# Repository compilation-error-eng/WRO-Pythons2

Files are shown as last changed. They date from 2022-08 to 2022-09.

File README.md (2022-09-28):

# WRO FUTURE ENGINEERS The Pythons 2 

This is a detailed documentation of our project in the WRO FUTURE ENGINEERS competition of my team that consist of 3 people and our coach Omar Khaled Elsayed . My name is Ahmed Elsayed and I am responsible for the programming of the robot , my teammates are Nour Eldin Raoof and Eyad Ahmed Nazary each are responsible for the mechanical and the electrical section of the robot respectively . We are from Egypt and are joining the WRO competition for the first time and I am going to explain the steps and procedures that went into creating our robot.

## Firstly: Our components
For seeing the blocks and moving accordingly we used the Openmv H7 plus camera module it is a cheap easy to buy camera module that is similar to the raspberry pi but is much cheaper here is a photo of it:

openmv1

>Link of components can be found at the end

For communicating with the camera module and order the motors to move accordingly we used an ordinary Arduino Nano 
A photo of it:

index

>Link can be found later

We used the l298 motor driver to move the motor forward and backwards and it is small and suitable for one motor which is required

f636e246-1f8f-4bf6-931c-e3b472912639 __CR00970600_PT0_SX970_V1___

For the battery we used a standard 12volt battery with 3600mah

For our steering mechanism we used a servo motor connected to a rod that controls the position of the robot.

YM2758-arduino-compatible-9g-micro-servo-motorImageMain-515 

We also used an IMU sensor to control the deviation of the robot from its origin point in certain turns 

imu sensor 

We used a stepdown buck converter DC to DC to convert the 12volts that are coming from the battery to 9 volts in order for the Arduino Nano to use it

buck convertor

## Links:

Arduino Nano:
https://store.arduino.cc/products/arduino-nano

l298 motordriver:
https://store.fut-electronics.com/products/l298-dual-motor-driver-module-2a

IMU sensor:
https://makerselectronics.com/product/imu-mpu-6050-gyroscope-accelerometer-sensor-module

buck cnovertor:
https://makerselectronics.com/product/xl4015-step-down-dc-module-with-cv-cc-control

servo motor:
https://makerselectronics.com/product/micro-servo-sg92r

openmv H7 R2 camera:
https://openmv.io/products/openmv-cam-h7-r2

## Explenation for the code:

we divided the code into steps :
- Blocks
- lines
- walls

ordered according to priority

I will now explain each step briefly:

### Blocks:

------------
we used a simple searching algorithm where the camera search in aspecified ROI (Region Of Intrest)
and applied a threshold for the camera to see only the specified color which is either Green or red if u want to see the blocks and that threshold can be changed in order to see diffrent colors and do diffrent tasks so we used this for the rest of the algorithm
, but there is a twist in the blocks part of the code it is important to make the blocks the highest priority so it can turn around it even if there is a line

### Lines:

------------
In the lines it was a little diffrent from the blocks because u have two lines with diffrent colours and u need to turn according to the first one the camera sees and u can simply do that with flags and counters ,make a counter that starts counting when it sees orange (or blue if u started in the opposite direction )
then if that counter gets high enough that means that he needs to turn the next time he sees a line otherwise dont turn and we also used the IMU MPU 6050 sensor to calculate degree of turn and made him turn only 45 degrees so he turns according to the block if there is one

### Walls:

------------
in the walls it was pretty simple but because of my camera was a little bugged it only saw one wall ond rarely sees the two lines togethor so i modified the 
original algorithm to suite my bugged camera which is always easier than getting a new camera i made , but isnt necessary, I write 3 conditions in total if the robot sees only the right wall it will position itself according to it , if it sees only the left wall it will also posistion itself accordingly  and if it sees the 2 walls togethor
(which rarely happens) this algorithm works but ofcourse it does have its bugs but i cant really afford a new camera so im sticking with this until i afford it

# electric schematic of the robot:

WRO schematic

# pictures of robot:

### Front view:

-----------------



### left view:

---------------



### Back view:

-----------------



### Right view:

----------------



### Top view:

--------------



### Bottom view:

-----------------



# Assembly of robot:

wro ass

-------------------------------------------------------------------------------------------------------------------

# finishing off:

It was a real plesure to join this competetion we didint place first like i wanted but i sure learned alot from this competition and i would love to join it again next year but this time ill definantly place first since i have enough determination and i have the amazing support of my coach youssef it was such a pleasure to join this and be part of a growing and fun community with like minded people who also have a burning passion for robotics

 ## A photo of us at the awarding ceremony after we placed third:
 
 FB_IMG_1664358030663
----------------------------------------------------------------------------------------------------------------------------------

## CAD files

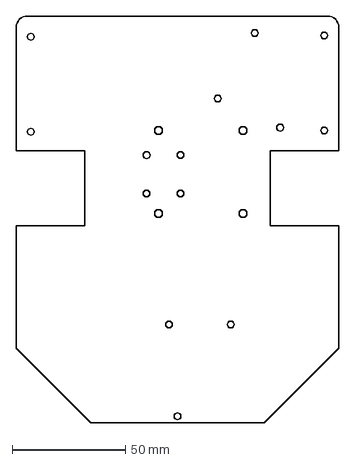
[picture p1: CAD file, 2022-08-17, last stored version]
W.R.O final isa.DXF
142.7 x 180.0 mm

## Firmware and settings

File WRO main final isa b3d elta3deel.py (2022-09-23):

# WRO- future engineers - By: The pythons 2 - Wed Jul 20 2022

import sensor, image, time, pyb
from pyb import UART
ledblue = pyb.LED(3)
ledred = pyb.LED(1)
ledgreen = pyb.LED(2)
threshold1 = [(35, 59, -44, -16, -46, 28)] #green threshold
threshold2 = [(20, 41, 6, 51, 6, 68)] #red threshold
thresholds_W = [(0, 8, -10, 9, -8, 11)] #wall threshold
thresholds_L=[(41, 69, 3, 32, 21, 51)]#orange line threshold
thresholds2_L = [(27, 77, -6, 20, -54, -15)]#blue line threshold
ROIl = [ (130,30,30,70, 0.7)]#left roi of wall
ROIR = [(0,30,30,70, 0.7)] #right roi of wall
ROI_L = [ (0,110,160,10, 0.7)] # blue orange line roi 20,150,320,70
middle_wall =[(20,40,120,35,0.7)] #middl wall roi
EXPOSURE_TIME_SCALE =2
sensor.reset()
sensor.set_pixformat(sensor.RGB565)
sensor.set_framesize(sensor.QQVGA)
sensor.set_auto_gain(False) # must be turned off for color tracking
sensor.set_auto_whitebal(False) # must be turned off for color tracking
sensor.set_auto_exposure(False,15000)
sensor.skip_frames(time = 500)
#current_exposure_time_in_microsecond  = sensor.get_exposure_o,us()
clock = time.clock()
#sensor.set_auto_exposure(False,  exposure_us=int(current_exposure_time_in_microsecond * EXPOSURE_TIME_SCALE))
sensor.set_auto_exposure(False,15000)
uart = UART(1, 115200)
greenflag = False
flag_orange = False
c =1150
flag_blue = False
leftwallgreenblock = False
left_wallflag = False
right_wallflag = False
redflag = False
blue_wall = False
green_wall = False
orange_greenline = False
red_wall = False
orange_wall = False
boflag = False
wallline_flag = False
wall_flag = False
orange_flag = False
blue_flag = False
corner_counter=0
uart.write("F")
while(True):

    clock.tick()
    img = sensor.snapshot()
    if corner_counter==4:
        uart.write("S")

    else:

        #img = img.gamma_corr(gamma = 0.3,contrast=18.0,brightness=0.05)
        #img.draw_rectangle(20,40,120,35,color=(0,0,255),thickness =2,fill=False)
        #img.draw_rectangle(0,110,160,10,color=(255,0,0),thickness =2,fill=False) #(200, 60, 120, 90, 0.7)
        #img.draw_rectangle(130,30,30,70,color=(255,0,0),thickness =2,fill=False) #(200, 60, 120, 90, 0.7)            # Note: OpenMV Cam runs about half as fast when connected
        #img.draw_rectangle(0,100,160,20,color=(0,255,0),thickness =2,fill=False) #(20, 180, 320, 40, 0.7)
        for m in middle_wall:
            greenblob = img.find_blobs(threshold1,pixel_threshld=500, area_threshold=400,merge=True)
            if greenblob:
                        #if greenblob[0].area() >= 5000:
                            #uart.write("B")
                            #print("area of blob to large going back")

                        print("green blob cx = ", greenblob[0].cx())
                        if orange_greenline == True:
                            if greenblob[0].cx() >=100:

                                uart.write("l")
                                time.sleep(0.1)
                                uart.write("F")
                            elif 80 < greenblob[0].cx() <100:
                                uart.write("L")
                                time.sleep(0.1)
                        if greenblob[0].cx() >= 130 :
                            print("forward green taree2ak salek")
                            uart.write("F")

                            time.sleep(0.2)
                        elif  greenblob[0].cx() < 30 :
                            print("backwarads then left")
                            #uart.write("b")
                            uart.write("g")
                            time.sleep(0.2)
                        elif 130 > greenblob[0].cx() >=30 :
                            img.draw_rectangle(greenblob[0].rect(),color=(0,255,0))
                            img.draw_cross(greenblob[0].cx(),greenblob[0].cy())

                            print("turn left")
                            uart.write("g")
                            time.sleep(0.1)
                            print("area of greenblob",greenblob[0].area())
                            greenflag = True
                            green_wall = True
                            #ledgreen.on()

            else:
                        greenflag = False
                        green_wall = False
                       # print("no green")
                        ledgreen.off()
            redblob = img.find_blobs(threshold2,pixel_threshld=500, area_threshold=400,merge=True)

            if redblob and redblob[0].cy() <= 60 and redblob[0].area()>350:
                        redflag = True
                        img.draw_rectangle(redblob[0].rect(),color=(255,0,0))
                        img.draw_cross(redblob[0].cx(),redblob[0].cy())
                        print("cy of redblob = ", redblob[0].cy())
                        if redblob[0].cx() > 100:
                            print("backwards then right red")
                            uart.write("b")
                            uart.write("R")
                            time.sleep(0.2)
                        elif redblob[0].cx() < 40:
                            print("forward red blob taree2ak salek")
                            uart.write("F")
                            time.sleep(0.1)
                        else:
                            uart.write("d")
                            time.sleep(0.2)
                            print("turn right red")
                            #uart.write("d")
                            #ledblue.on()
                            #ledred.on()
                            time.sleep(0.1)
                            print("area of redblob",redblob[0].area())
                            red_wall = True
            else:
                        red_wall = False
                        redflag = False
                       # print("no red")
                        ledred.off()
                        ledblue.off()

        if redflag or greenflag :
            wallline_flag = False
        else:
            wallline_flag = True

        for r in ROI_L:
            if c>=500:
                orange_wall = False
                blue_wall = False
            orange_lines = img.find_blobs(thresholds_L,roi=r[0:4], pixelthreshold=100, areathreshold=500)
            blue_lines = img.find_blobs(thresholds2_L, roi=r[0:4], pixelthreshold=100, areathreshold=500)
            if orange_lines  and c>=500 and orange_lines[0].cy() > 100:
                 orange_wall = True
                 c=0
                 c+=1
                 orange_greenline = True
                 ledgreen.on()
                 ledblue.on()
                 print("cy of orange =" , orange_lines[0].cy())
                 if wallline_flag:

                    print("c=",c)
                    print("orange line area = ",orange_lines[0].area())
                    ledred.on()
                    ledgreen.on()
                    img.draw_rectangle(orange_lines[0].rect())
                    img.draw_cross(orange_lines[0].cx(),orange_lines[0].cy())
                    print("orange line found going right")
                    uart.write("O")
                    corner_counter+=1
                    #time.sleep(0.1)

                    wall_flag = False
            elif blue_lines  and c>=500:
                blue_wall = True
                c=0
                c+=1
                print("i saw blue")
                print("wall line flag = ", wallline_flag)
                print("c = ", c)
                if wallline_flag:
                    img.draw_rectangle(blue_lines[0].rect())
                    img.draw_cross(blue_lines[0].cx(),blue_lines[0].cy())
                    ledblue.on()
                    print("blue light found turning left")
                    uart.write("F")
                    time.sleep(0.5)
                    uart.write("B")
                    time.sleep(0.1)
                    corner_counter+=1
                    print("c=",c)
                    flag_blue = True
                    blue_wall = True
                    wall_flag = False
            else:
                    ledblue.off()
                    ledred.off()
                    ledgreen.off()
                    wall_flag = True

        if wall_flag == True and wallline_flag == True :
            for l in ROIR:
                    left_wall = img.find_blobs(thresholds_W,roi=l[0:4],pixelthreshold=800, areathreshold=450,merge=True)
                    if left_wall:
                        maxleftwall = max(left_wall, key=lambda b:b.area())
                        leftwallgreenblock = True
                        if  maxleftwall.area()>500 :
                            green_left = True
                            area_leftwall = maxleftwall.area()
                            print("area left wall",area_leftwall)
                            img.draw_rectangle(maxleftwall.rect())
                            img.draw_cross(maxleftwall.cx(), maxleftwall.cy())
                            c+=1
                            print("c=",c)
                            left_wallflag = True
                        else:
                            left_wallflag = False
                            area_leftwall = 0

            for s in ROIl :
                    right_wall = img.find_blobs(thresholds_W ,roi=s[0:4], pixelthreshold=500, areathreshold=450, merge=True)
                    if right_wall:
                        maxrightwall = max(right_wall, key=lambda b:b.area())
                        if  maxrightwall.area()>500 :
                            red_right = True
                            area_rightwall = maxrightwall.area()
                            print("area right wall",area_rightwall)
                            img.draw_rectangle(maxrightwall.rect())
                            img.draw_cross(maxrightwall.cx(), maxrightwall.cy())
                            c+=1
                            print("c=",c)
                            right_wallflag = True
                        else:
                            right_wallflag = False
                            area_rightwall = 0
            if right_wallflag == False and left_wallflag == True:
                    c+=1
                    if 1100>area_leftwall >760:
                        uart.write("r")
                        print("right without right wall")
                    elif area_leftwall >=1100:
                        uart.write("R")
                        print("hard right without right u turn")
                    elif 750>=area_leftwall >680:
                        uart.write("F")
                        print("forward without right wall")

            elif right_wallflag == True and left_wallflag == False:
                    c+=1
                    if 900 > area_rightwall >=650:
                        uart.write("l")
                        print("left without left wall")
                    elif area_rightwall >900:
                        uart.write("L")
                        print("hard left without left u turn")
                    elif 650>area_rightwall >500:
                        uart.write("F")
                        print("forward without left wall")
            elif right_wallflag == True and left_wallflag == True:
                    wall_diff = area_rightwall-area_leftwall
                    c+=1
                    if area_rightwall >=1000 and area_leftwall >= 1000:
                        if green_wall:
                            uart.write("b")
                            uart.write("R")
                            time.sleep(0.1)
                            uar.write("F")
                            print("all black infront of me green going left")
                        elif red_wall:
                            uart.write("b")
                            uart.write("L")
                            time.sleep(0.1)
                            uar.write("F")
                            print("all black infront of me red going left")
                        elif blue_wall:
                            uart.write("b")
                            uart.write("B")
                            print("all black infront of me going left")

                        elif orange_wall == True:
                            uart.write("b")
                            uart.write("O")
                            print("all black infront of me going right")

                    else:
                        print("wall diff = ",wall_diff)
                        if wall_diff >=700:
                                uart.write("L")
                                print("hard left turn 2 walls present")
                        elif wall_diff <= -500:
                                uart.write("R")
                                print("hard right turn 2 walls present")
                        elif 700>wall_diff >50:
                                print("turn left wall")
                                uart.write("l")
                               # c+=1
                        elif -300>wall_diff > -500:
                                print("turn right wall")
                                uart.write("r")
                                #c+=1
                        elif -300<=wall_diff< 50:
                                print("forward wall")
                                uart.write("F")
                                #c+=1

            else:
                 wall_diff =0

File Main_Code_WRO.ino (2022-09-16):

#include<Servo.h>
Servo myservo;
int IN3 = 7;
int IN4= 8;
int i=0;
int ENB = 5;
bool flag = true;
int yaw;
int yaw_initial;
char byteRead = ' ';
bool LR=false;
void setup() {
  
    Serial.begin(115200);
    myservo.attach(12);
    pinMode(IN3 , OUTPUT);
    pinMode(IN4 ,OUTPUT);
    pinMode(ENB , OUTPUT);
    imu_setups();
}

void loop() {
      yaw =imu_loop();
      //Serial.println(yaw);
       if(Serial.available()){
         //Serial.println("work");
            byteRead = Serial.read();
            //Serial.println(byteRead);
            if(flag == false){
              digitalWrite(13, HIGH);
             if(i<45){
            if(LR == false) right();
            else left();
              
             // Serial.println("going right");
              if (yaw != yaw_initial) {
                yaw_initial = yaw;
                i ++;
                //Serial.println(i);
              }
            }
            else{
               
                stops();
                flag=true;
                i=0; 
                //Serial.println("stop");
            }
            if (byteRead == 'R' || byteRead == 'L' ){
              flag = true;
              i=0;
            }
          }
          else{
            digitalWrite(13, LOW);
            if(byteRead == 'B'){
                  if(flag){
                  yaw_initial = yaw;
                  flag = false;
                  LR=true;
                  }
            }
            else if(byteRead == 'O'){
               if(flag ){
              //digitalWrite(13, HIGH);
              yaw_initial = yaw;
              flag = false;
              LR=false;
              }
            
            else if(byteRead == 'R'){
                  right();
                  //Serial.println("turn right");
                  flag=true;
            }
            
            }
            else if(byteRead =='r'){
              right_wall();
              //Serial.println("right wall");
              
            }
            else if(byteRead == 'S'){
              stops();
            }
            else if(byteRead =='l'){
              left_wall();
              //Serial.println("left wall");
              
            }
            else if (byteRead == 'L'){
              left();
              //Serial.println("turn left");
              flag=true;
            }
            else if(byteRead == 'F'){
              forward();
              //Serial.println("forward");
            }
            else if (byteRead == 'b'){
              backwards();
              delay(100);
            }
      }
          }

}
//-88  -1 --->1

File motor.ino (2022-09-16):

void right(){
    myservo.write (155);
  digitalWrite(IN3 , HIGH); //IN1 -->HIGH,IN2-->LOW   backwards
  digitalWrite(IN4 , LOW);  //IN1 -->LOW , IN2 -->HIGH forward
  analogWrite(ENB ,255);
}
void stops(){
  myservo.write(110);
  analogWrite(ENB,0);
}
void left(){
    myservo.write(85);
  digitalWrite(IN3 , HIGH); //IN1 -->HIGH,IN2-->LOW   backwards
  digitalWrite(IN4 , LOW);  //IN1 -->LOW , IN2 -->HIGH forward
  analogWrite(ENB ,255);
}
void forward(){
  myservo.write(110);
  digitalWrite(IN3, HIGH);
  digitalWrite(IN4, LOW);
  analogWrite(ENB ,255);
}
void left_wall(){
  myservo.write(105);
  digitalWrite(IN3 , HIGH); //IN1 -->HIGH,IN2-->LOW   backwards
  digitalWrite(IN4 , LOW);  //IN1 -->LOW , IN2 -->HIGH forward
  analogWrite(ENB ,255);
}
void right_wall(){
  myservo.write(125);
  digitalWrite(IN3 , HIGH); //IN1 -->HIGH,IN2-->LOW   backwards
  digitalWrite(IN4 , LOW);  //IN1 -->LOW , IN2 -->HIGH forward
  analogWrite(ENB ,255);
}
void backwards(){
  myservo.write(110);
  digitalWrite(IN3, LOW);
  digitalWrite(IN4, HIGH);
  analogWrite(ENB ,255);
} 

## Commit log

2022-08-17 design for WRO robot
    [W.R.O final isa.DXF]
2022-08-22 arduino code
2022-09-16 IMU
    IMU code
2022-09-16 main arduino code
2022-09-16 motor codes
2022-09-19 code for second arduino nano
    the IMU sensor was getting interrupted by the traffic on the first arduino so we made a second arduino code
2022-09-19 Code for IMU sensor
2022-09-22 fuck it
    [W.R.O final isa.DXF]
